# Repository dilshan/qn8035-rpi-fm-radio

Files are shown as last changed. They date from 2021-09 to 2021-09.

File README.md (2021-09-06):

# QN8035 based Raspberry Pi FM radio receiver.

[QN8035](https://datasheetspdf.com/pdf-down/Q/N/8/QN8035_Quintic.pdf) is a single-chip stereo FM radio receiver IC designed by the *Quintic Corporation*. This receiver supports the FM broadcast band ranging from 60MHz to 108MHz. 

This repository contains a *[Raspberry Pi](https://www.raspberrypi.org/products/raspberry-pi-3-model-b/)* base QN8035 receiver to receive FM stereo broadcasts from 88MHz to 108MHz.

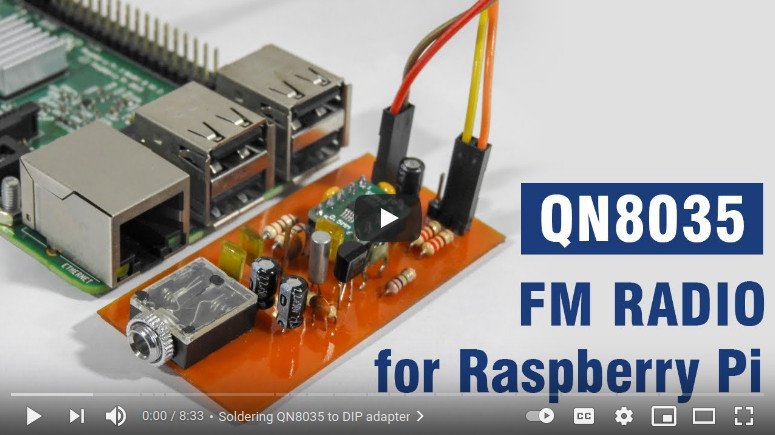
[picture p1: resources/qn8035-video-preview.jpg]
Video preview (https://www.youtube.com/watch?v=qJ5dKJD2EvY)


The hardware part of this receiver consists of a QN8035 tuner and a 32.768kHz oscillator circuit. These circuits are designed to work with a 3.3V power supply.

The prototype version of this tuner designs with a single-sided PCB. All the schematics and *KiCAD* PCB design files are available in this repository. The Gerber files of this PCB are available to download at the release section of this repository.

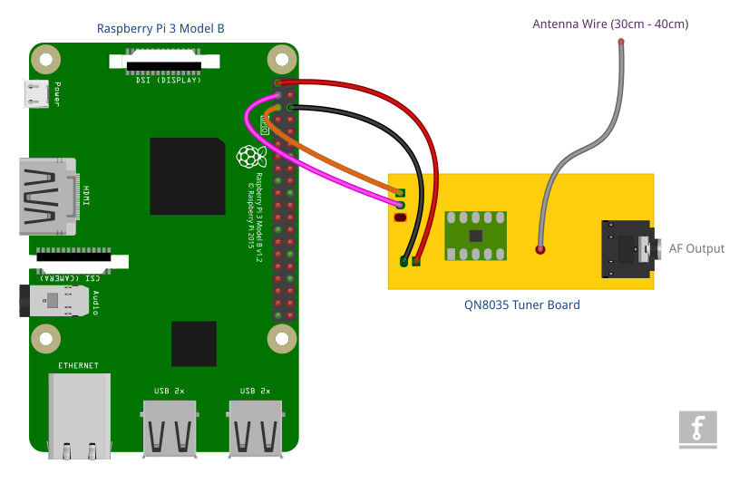
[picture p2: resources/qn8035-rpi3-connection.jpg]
QN8035 and Raspberry Pi3 connection diagram


The QN8035 uses the I2C bus to communicate with the host system. The tuner application develops with this system utilizes I2C channel 1 (*Raspberry Pi* header Pin 3 and 5) to communicate with the QN8035. The control software presents in this repository is designed to work with the *Raspberry Pi* operating system and is set to run on May 7th, 2021 (*Buster*), or the latest releases.

The tuner application provided in this release supports the following features:

 - Manual and automatic station scanning. 
 - Decode RDS PS (program service) data. 
 - Volume control.
 - Display RSSI and SNR readings receive from the tuner.

The control application of this receiver develops using *GCC* and *[WiringPi](http://wiringpi.com/)* library. 

The complete construction and configuration steps of this tuner show in the video above.

This is an open-source hardware project. All schematics, design files, and PCB layouts have been released under the [Creative Commons Attribution 4.0 International](https://creativecommons.org/licenses/by/4.0/) license. The control software is released under the terms of the [MIT License](https://opensource.org/licenses/MIT).

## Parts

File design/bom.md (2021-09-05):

## QN8035 Tuner - Bill of materials

| Designator | Value | Quantity |
|---|---|---|
| C1 | 100pF | 1 |
| C2, C3 | 2.2μF / 16V | 2 |
| C4 | 0.01μF | 1 |
| C5, C6 | 0.001μF | 2 |
| C7 | 10μF / 16V | 1 |
| C8, C9 | 0.1μF | 2 |
| C10 | 56pF | 1 |
| C11 | 22pF | 1 |
| R1, R4 | 100Ω (1/4W Carbon film resistor - 5%) | 2 |
| R2, R3 | 220Ω (1/4W Carbon film resistor - 5%) | 2 |
| R5 | 1MΩ (1/4W Carbon film resistor - 5%) | 1 |
| R7 | 10MΩ (1/4W Carbon film resistor - 5%) | 1 |
| Y1 | 32.768kHz Crystal (AT310) | 1 |
| Q1 | 2N3904 (TO-92) | 1 |
| U1 | QN8035 (MSOP10) | 1 |
| J1 | PJ324 - 5 Pin 3.5mm Stereo audio jack socket | 1 |
| J2 | 2-Pin, 2.54mm Pin Header | 1 |
| J3 | 3-Pin, 2.54mm Pin Header | 1 |
| AE1 | 1-Pin, 2.54mm Pin Header | 1 |
| | MSOP10 (0.5mm) to DIP10 converter PCB | 1 |

Except for *U1*, all the components are standard through-hole type components.

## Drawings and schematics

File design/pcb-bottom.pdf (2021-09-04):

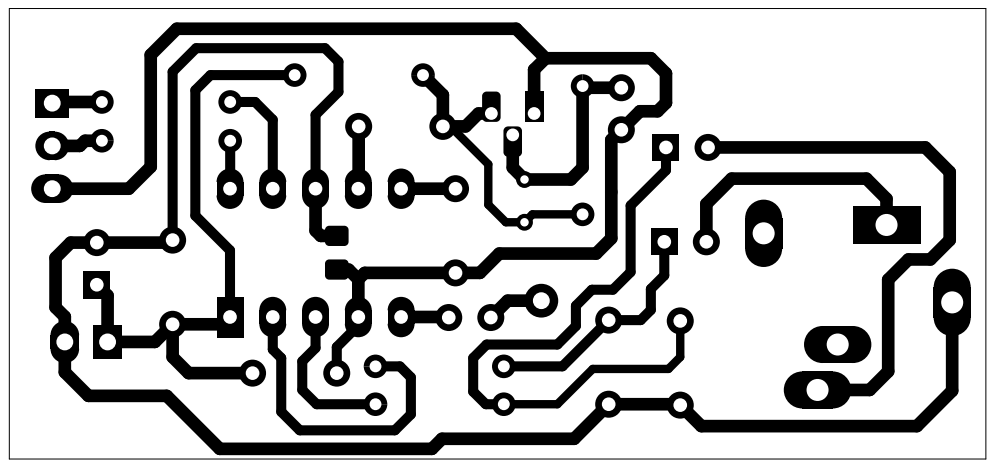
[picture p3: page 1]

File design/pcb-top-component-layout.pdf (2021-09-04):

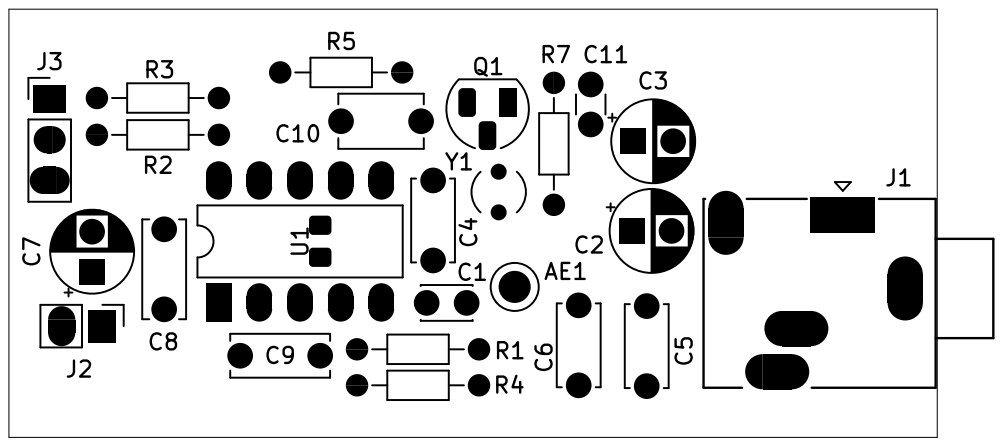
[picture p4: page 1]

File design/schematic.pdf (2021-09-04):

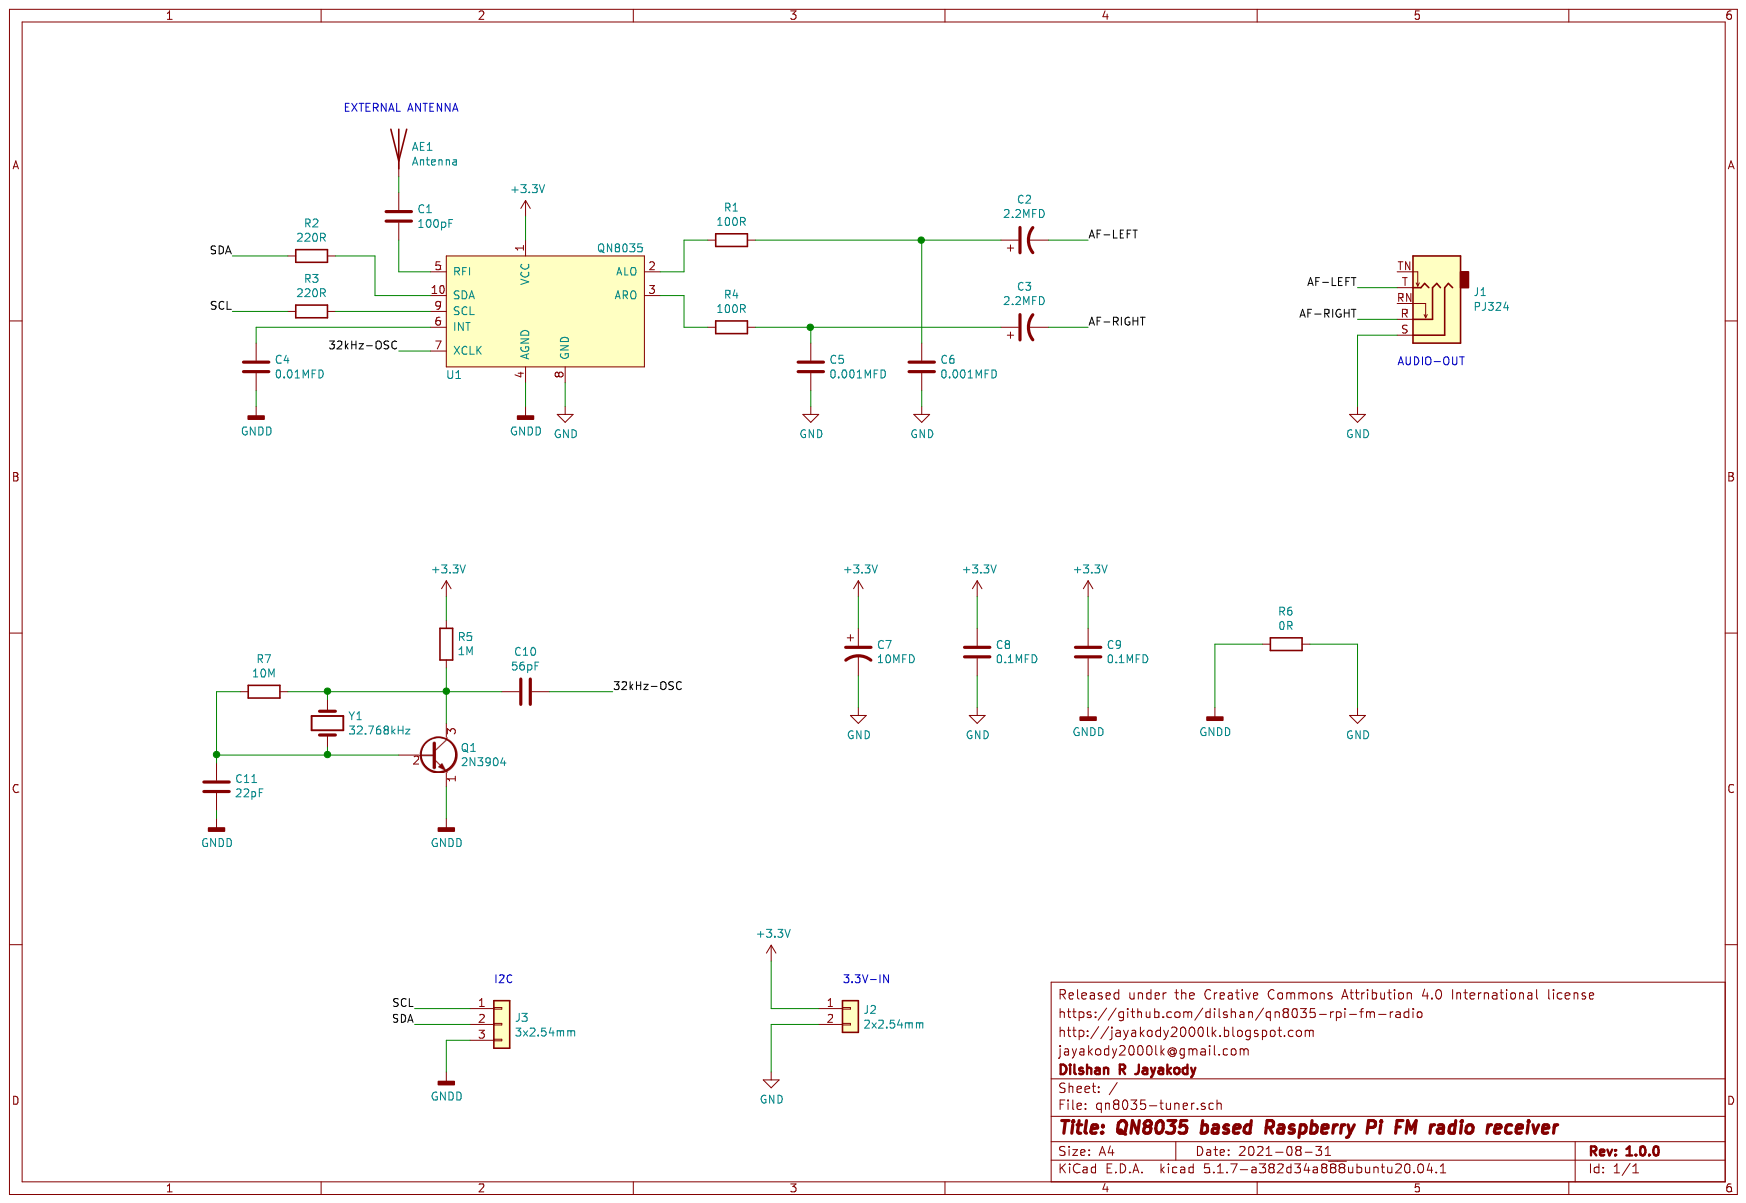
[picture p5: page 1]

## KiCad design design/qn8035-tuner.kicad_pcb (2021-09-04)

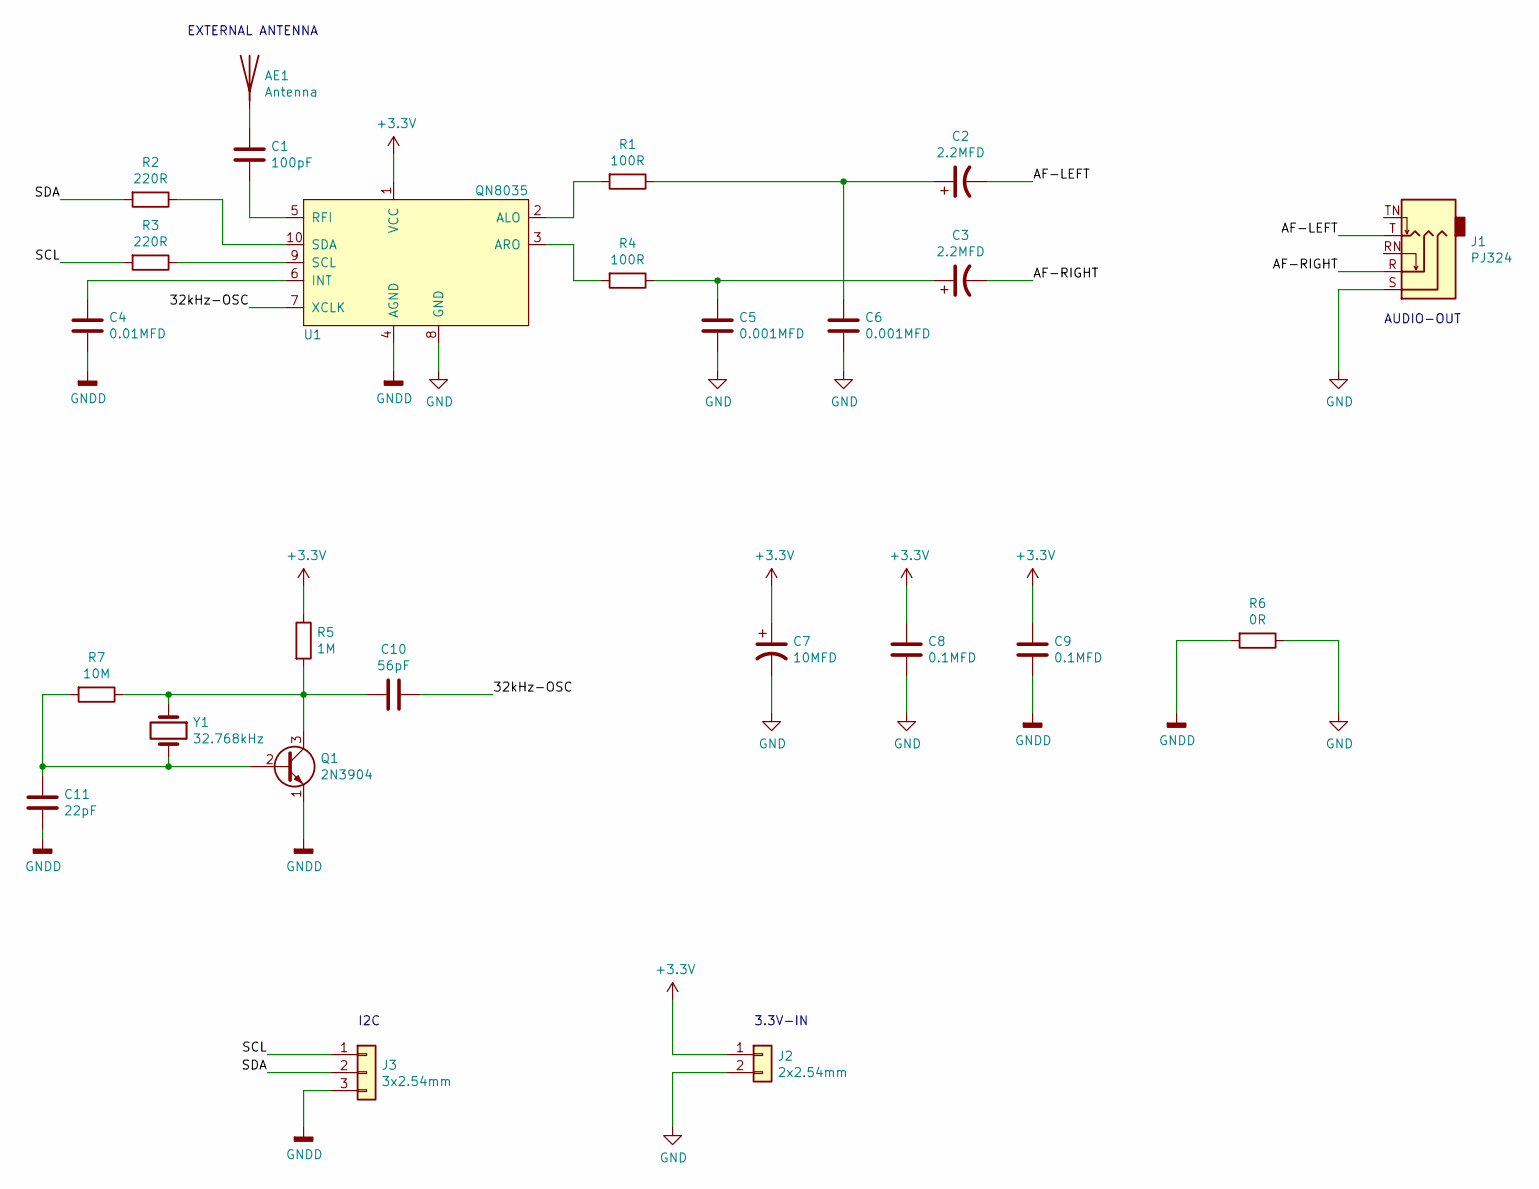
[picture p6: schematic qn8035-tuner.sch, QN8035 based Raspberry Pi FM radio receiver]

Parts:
AE1: Antenna; TestPoint_Loop_D2.50mm_Drill1.0mm
C1: 100pF; C_Disc_D3.0mm_W2.0mm_P2.50mm
C2, C3: 2.2MFD; CP_Radial_D5.0mm_P2.50mm
C4: 0.01MFD; C_Disc_D5.0mm_W2.5mm_P5.00mm
C5, C6: 0.001MFD; C_Disc_D5.0mm_W2.5mm_P5.00mm
C7: 10MFD; CP_Radial_D5.0mm_P2.50mm
C8, C9: 0.1MFD; C_Disc_D6.0mm_W2.5mm_P5.00mm
C10: 56pF; C_Disc_D5.1mm_W3.2mm_P5.00mm
C11: 22pF; C_Disc_D3.0mm_W1.6mm_P2.50mm
J1: PJ324; Jack_3.5mm_Ledino_KB3SPRS_Horizontal
J2: 2x2.54mm; PinHeader_1x02_P2.54mm_Vertical
J3: 3x2.54mm; PinHeader_1x03_P2.54mm_Vertical
Q1: 2N3904; TO-92_HandSolder
R1, R4: 100R; R_Axial_DIN0204_L3.6mm_D1.6mm_P7.62mm_Horizontal
R2, R3: 220R; R_Axial_DIN0204_L3.6mm_D1.6mm_P7.62mm_Horizontal
R5: 1M; R_Axial_DIN0204_L3.6mm_D1.6mm_P7.62mm_Horizontal
R6: 0R; R_0805_2012Metric_Pad1.20x1.40mm_HandSolder
R7: 10M; R_Axial_DIN0204_L3.6mm_D1.6mm_P7.62mm_Horizontal
U1: QN8035; DIP-10_W7.62mm_LongPads
Y1: 32.768kHz; Crystal_AT310_D3.0mm_L10.0mm_Vertical

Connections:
+3V3: C7.1, C8.1, C9.1, J2.1, R5.1, U1.1 (VCC)
/32kHz-OSC: C10.1, U1.7 (XCLK)
/AF-LEFT: C2.2, J1.T
/AF-RIGHT: C3.2, J1.R
/SCL: J3.1, R3.2
/SDA: J3.2, R2.2
GND: C5.2, C6.2, C7.2, C8.2, J1.S, J2.2, R6.1, U1.8 (GND)
GNDD: C4.2, C9.2, C11.1, J3.3, Q1.1 (E), R6.2, U1.4 (AGND)
unnamed: AE1.1, C1.1
unnamed: C1.2, U1.5 (RFI)
unnamed: C2.1, C6.1, R1.1
unnamed: C3.1, C5.1, R4.1
unnamed: C4.1, U1.6 (INT)
unnamed: C10.2, Q1.3 (C), R5.2, R7.1, Y1.1
unnamed: C11.2, Q1.2 (B), R7.2, Y1.2
unnamed: R1.2, U1.2 (ALO)
unnamed: R2.1, U1.10 (SDA)
unnamed: R3.1, U1.9 (SCL)
unnamed: R4.2, U1.3 (ARO)

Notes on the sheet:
AUDIO-OUT
EXTERNAL ANTENNA
I2C
3.3V-IN

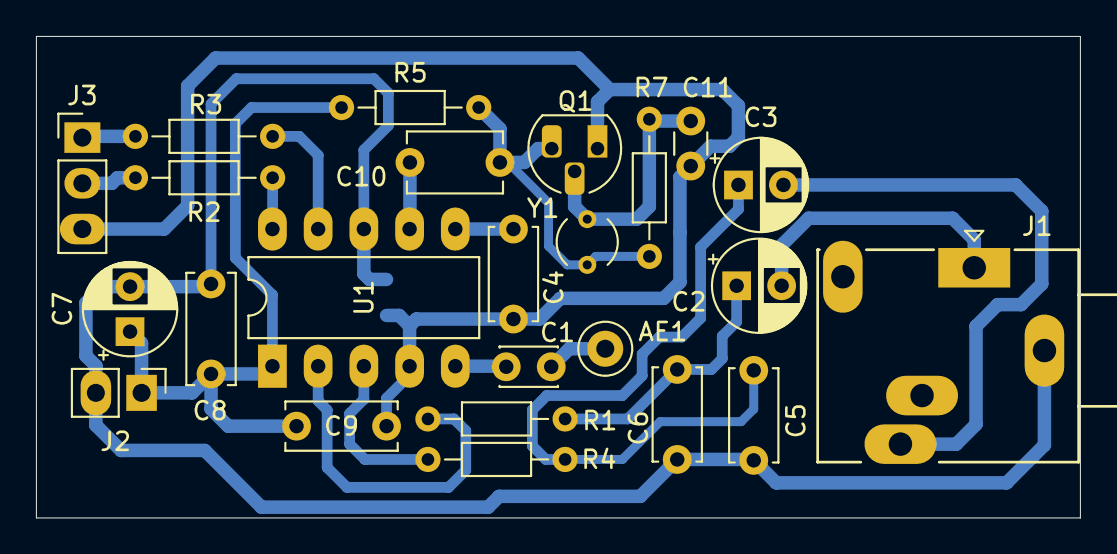
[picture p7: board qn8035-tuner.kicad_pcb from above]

Board: 2 copper layers, 58.0 x 26.8 mm, 25 parts (1 on the bottom side), 19 nets.

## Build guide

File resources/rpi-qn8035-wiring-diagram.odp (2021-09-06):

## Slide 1

QN8035 Tuner and Raspberry Pi 3 connection diagram


Terminal | Raspberry Pi Pin | QN8035 Pin
SDA | 3 | J3 - 2
SCL | 5 | J3 - 1
VCC (3.3V) | 1 | J2 - 1
GND | 6 | J2 - 2

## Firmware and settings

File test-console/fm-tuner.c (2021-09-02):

/*********************************************************************************
 * Copyright 2021 Dilshan R Jayakody. [jayakody2000lk@gmail.com]                 *
 *                                                                               *
 * Permission is hereby granted, free of charge, to any person obtaining a       *
 * copy of this software and associated documentation files (the "Software"),    *
 *  to deal in the Software without restriction, including without limitation    *
 * the rights to use, copy, modify, merge, publish, distribute, sublicense,      *
 * and/or sell copies of the Software, and to permit persons to whom the         *
 * Software is furnished to do so, subject to the following conditions:          *
 *                                                                               *
 * The above copyright notice and this permission notice shall be included in    *
 * all copies or substantial portions of the Software.                           *
 *                                                                               *
 * THE SOFTWARE IS PROVIDED "AS IS", WITHOUT WARRANTY OF ANY KIND, EXPRESS OR    *
 * IMPLIED, INCLUDING BUT NOT LIMITED TO THE WARRANTIES OF MERCHANTABILITY,      *
 * FITNESS FOR A PARTICULAR PURPOSE AND NONINFRINGEMENT. IN NO EVENT SHALL THE   *
 * AUTHORS OR COPYRIGHT HOLDERS BE LIABLE FOR ANY CLAIM, DAMAGES OR OTHER        *
 * LIABILITY, WHETHER IN AN ACTION OF CONTRACT, TORT OR OTHERWISE, ARISING FROM, *
 * OUT OF OR IN CONNECTION WITH THE SOFTWARE OR THE USE OR OTHER DEALINGS IN     *
 * THE SOFTWARE.                                                                 *
 * *******************************************************************************
 *                                                                               *
 * Test Application for QN8035 tuner (for Raspberry Pi platform).                *
 *                                                                               *
 *********************************************************************************/

#include <stdio.h>
#include <unistd.h>
#include <errno.h>
#include <string.h>
#include <math.h>
#include <termio.h>
#include <stdlib.h>
#include <ctype.h>

// https://github.com/WiringPi/WiringPi
#include <wiringPiI2C.h>

#include "fm-tuner.h"

// Length of the dummy string which is created to avoid garbage characters in info line.
#define dummyLineSize   100

// Size of the RDS buffer.
#define RDS_INFO_MAX_SIZE 16

#define SET_REG(r,v)    wiringPiI2CWriteReg8(fd,r,v)
#define GET_REG(r)      wiringPiI2CReadReg8(fd,r)

#define FREQ_TO_WORD(f) ((USHORT)((f - 60) / 0.05))
#define WORD_TO_FREQ(w) (((DOUBLE)w * 0.05) + 60)

CHAR rdsInfo[RDS_INFO_MAX_SIZE], tempRDSBuffer[RDS_INFO_MAX_SIZE];
INT fd;
USHORT currentFreq;
UCHAR volume;

INT main()
{                
    UCHAR editMode;
    CHAR keyVal;
    DOUBLE freq;
    USHORT freqWord;
    CHAR dummyLine[dummyLineSize];

    volume = REG_VOL_CTL_MAX_ANALOG_GAIN;
    editMode = 1;
    
    // Initialize I2C connection with QN8035 tuner.
    fd = wiringPiI2CSetup(QN8035_ADDRESS);
    if(fd < 0)
    {
        // I2C setup error, may be I2C connection to QN8035 is faulty?
        printf("\nUnable to initialize the QN8035 receiver: %s\n", strerror(errno));
        return 1;
    }

    // Check for valid QN8035 tuner.
    if(GET_REG(REG_CID2) != QN8035_ID)
    {
        // Invalid chip ID detected!
        printf("\nInvalid/unsupported QN8035 chip ID\n");
        return 1;
    }

    printf("initializing QN8035 tuner...");

    // Reset all registers of QN8035 tuner.
    SET_REG(REG_SYSTEM1, REG_SYSTEM1_SWRST);
    sleep(1);

    // Set channel to 88.0MHz and enable receiving mode.
    setTunerFrequency(FREQ_TO_WORD(88.0));

    // Sets volume control gain to 0dB.
    SET_REG(REG_VOL_CTL, volume);

    // Create dummy string to avoid garbage characters in info line.
    memset(dummyLine, ' ', dummyLineSize - 2);
    dummyLine[dummyLineSize - 1] = 0;
    
    while(1)
    {
        // Check for frequency edit mode flag.
        if(editMode)
        {
            // Edit mode to enter frequency to tune the QN8035 tuner.
            if(getFrequency(&freq))
            {
                // Error or user request application termination.
                break;
            }

            // Tune receiver to the specified frequency.
            freqWord = FREQ_TO_WORD(freq);
            setTunerFrequency(freqWord);            

            printf("[C] Change Frequency   [<] Scan Down   [>] Scan Up   [-] Volume Up   [+] Volume Down   [Q] Quit\n");

            // Leaving edit mode.
            editMode = 0;
            resetRDSInfo();
        }

        // Check for key press events.
        if(isKeyPress())
        {            
            keyVal = getchar();              
            fflush(stdout);   

            printf("\r%s", dummyLine);  
            fflush(stdout);    

            switch (keyVal)
            {
                case 0x43:
                case 0x63:
                    // [C] key : Edit frequency.
                    editMode = 1;                    
                    break; 
                case 0x51:
                case 0x71:
                    // [Q] key : Exit.
                    shutdownTuner();
                    printf("\n");
                    exit(0);
                    break;   
                case 0x2E:
                    // [>] key : Scan Up.
                    scanFrequencyUp();   
                    resetRDSInfo();
                    break; 
                case 0x2C:
                    // [<] key : Scan Down.
                    scanFrequencyDown();
                    resetRDSInfo();
                    break;  
                case 0x3D:
                    // [+] key : Volume Up.
                    updateVolume(1);
                    break;
                case 0x2D:
                    // [-] key : Volume Down.
                    updateVolume(0);
                    break;  
                default:
                    break;
            }
        }

        showRXInfo();
        usleep(1500);
    }

    return 0;
}

VOID setTunerFrequency(USHORT tFreq)
{
    SET_REG(REG_CH, (tFreq & 0xFF));                // Lo
    SET_REG(REG_CH_STEP, ((tFreq >> 8) & 0x03));    // Hi
    usleep(100);
    SET_REG(REG_SYSTEM1, REG_SYSTEM1_CCA_CH_DIS | REG_SYSTEM1_RXREQ | REG_SYSTEM1_RDSEN);

    // Update global (default) frequency value.
    currentFreq = tFreq;
}
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

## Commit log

2021-09-04 Add KiCAD design files and schematics.
    [qn8035-tuner.kicad_pcb, qn8035-tuner.sch]
2021-09-05 Add initial version of BOM file.
2021-09-05 Add Raspberry Pi3 connection diagrams.
    [qn8035-rpi3-connection.fzz]
2021-09-05 Update BOM file with package details.

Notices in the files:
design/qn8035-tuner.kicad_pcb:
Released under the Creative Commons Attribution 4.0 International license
